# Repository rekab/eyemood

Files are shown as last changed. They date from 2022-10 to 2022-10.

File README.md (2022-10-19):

# eyemood

Video of a robot costume (https://www.youtube.com/watch?v=6ULORxLHcV8)

A thing to animate NeoPixel ring(s) with 12 LEDs.

Takes 5 input buttons (white, red, green, blue, yellow) that have LED
lights.

Together these represent the bits in a 5-bit integer, which is used
as an index of 32 different animations ("Steppers").

Each of the buttons have an LED that's lit based on if their bit is
a 1 (on) or 0 (off). This bit pattern changes by counting upwards by one
every ~8.7 seconds. It wraps back to 0 after 31.

## Requirements

### Hardware

* Tested on an Arduino UNO R3
* Two [NeoPixel 12 LED Rings](https://www.adafruit.com/product/1643)
* A 1000µF (6.3V or higher) capacitor on the power to the NeoPixel rings.
* A 470Ω resistor on the data pin to the NeoPixel rings.
* Five buttons. I used 5 diffent colors of
  [Mini LED Arcade Button - 24mm](https://www.adafruit.com/product/3432)
* [Micro USB pinboard](https://www.amazon.com/Pinboard-MELIFE-Interface-Adapter-Breakout/dp/B07W6T97HZ/)
  for powering the NeoPixel rings

### Arduino Libraries

* Reactduino (https://github.com/Reactduino/Reactduino)
* Adafruit Neopixel (1.10.5 https://github.com/adafruit/Adafruit\_NeoPixel)

### Wiring and Pins

|  Color | Purpose | Pin Number |
|:---:|:---:|:---:|
| Black  | white switch  | 11 |
| White  | white LED | 10 |
| Gray | green switch  | 9 |
| Purple | blue switch | 8 |
| Blue | blue LED | 7 |
| Green  | green LED | 6 |
| Yellow | yellow LED | 5 |
| Orange | yellow switch | 4 |
| Red | red LED | 3 |
| Brown  | red switch | 2 |

External power [must be connected to common ground](https://learn.adafruit.com/adafruit-neopixel-uberguide/basic-connections).

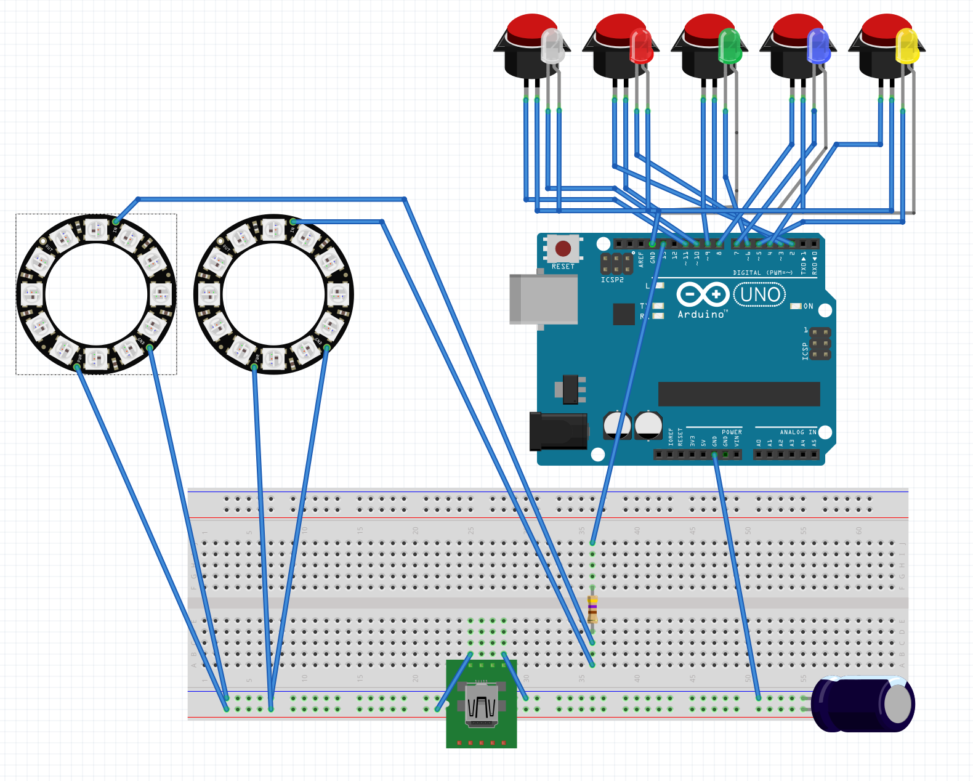
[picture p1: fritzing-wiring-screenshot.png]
Fritzing wiring diagram


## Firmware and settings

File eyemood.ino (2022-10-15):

/**
  * A thing to animate NeoPixel Ring(s) with 12 LEDs.
  *
  * Takes 5 input buttons (white, red, green, blue, yellow) that have LED
  * lights.
  *
  * Together these represent the bits in a 5-bit integer, which is used
  * as an index of 32 different animations ("Steppers").
  *
  * Each of the buttons have an LED that's lit based on if their bit is
  * a 1 (on) or 0 (off). This bit pattern changes by counting upwards by one
  * every ~8.7 seconds. It wraps back to 0 after 31.
  *
  * With debugging log statements this barely fit on an Arduino Uno, so they've
  * been mostly removed.
  *
  * 2022-10-02: Uploaded and put into costume. Not yet fastened down.
  */
#include <Reactduino.h>
#include <Adafruit_NeoPixel.h>

#define REPEAT_DELAY_MS 50
#define STEPS_UNTIL_CHANGE 175
#define BUTTON_DEBOUNCE_DELAY_MS 150

#define WHITE_MOOD_BUTTON_LED_PIN 10
#define WHITE_MOOD_BUTTON_SWITCH_PIN 11
#define WHITE_MOOD_BUTTON_SELECTOR_VALUE 4

#define RED_MOOD_BUTTON_LED_PIN 3
#define RED_MOOD_BUTTON_SWITCH_PIN 2
#define RED_MOOD_BUTTON_SELECTOR_VALUE 3

#define GREEN_MOOD_BUTTON_LED_PIN 6
#define GREEN_MOOD_BUTTON_SWITCH_PIN 9
#define GREEN_MOOD_BUTTON_SELECTOR_VALUE 2

#define BLUE_MOOD_BUTTON_LED_PIN 7
#define BLUE_MOOD_BUTTON_SWITCH_PIN 8
#define BLUE_MOOD_BUTTON_SELECTOR_VALUE 1

#define YELLOW_MOOD_BUTTON_LED_PIN 5
#define YELLOW_MOOD_BUTTON_SWITCH_PIN 4
#define YELLOW_MOOD_BUTTON_SELECTOR_VALUE 0

#define EYES_PIN 13
#define NUM_NEOPIXEL_PIXELS 12

#define COLOR_RED Adafruit_NeoPixel::Color(255, 0, 0)
#define COLOR_GREEN Adafruit_NeoPixel::Color(0, 255, 0)
#define COLOR_BLUE Adafruit_NeoPixel::Color(0, 0, 255)
#define COLOR_BLACK Adafruit_NeoPixel::Color(0, 0, 0)
#define COLOR_CYAN Adafruit_NeoPixel::Color(0, 150, 150)
#define COLOR_LIGHT_PURPLE Adafruit_NeoPixel::Color(200, 0, 100)
#define COLOR_WHITE Adafruit_NeoPixel::Color(255, 255, 255)


// Parameter 1 = number of pixels in strip
// Parameter 2 = Arduino pin number (most are valid)
// Parameter 3 = pixel type flags, add together as needed:
//   NEO_KHZ800  800 KHz bitstream (most NeoPixel products w/WS2812 LEDs)
//   NEO_KHZ400  400 KHz (classic 'v1' (not v2) FLORA pixels, WS2811 drivers)
//   NEO_GRB     Pixels are wired for GRB bitstream (most NeoPixel products)
//   NEO_RGB     Pixels are wired for RGB bitstream (v1 FLORA pixels, not v2)
Adafruit_NeoPixel eyes = Adafruit_NeoPixel(NUM_NEOPIXEL_PIXELS, EYES_PIN, NEO_GRB + NEO_KHZ800);
// IMPORTANT: To reduce NeoPixel burnout risk, add 1000 uF capacitor across
// pixel power leads, add 300 - 500 Ohm resistor on first pixel's data input
// and minimize distance between Arduino and first pixel.  Avoid connecting
// on a live circuit...if you must, connect GND first.

// Current animation being run.
uint8_t curStepper = 0;
// Steps since the stepper changed
uint32_t stepsSinceChange = 0;

uint8_t buttonToPinMap[5] = {
  /* button0: */ YELLOW_MOOD_BUTTON_LED_PIN,
  /* button1: */ BLUE_MOOD_BUTTON_LED_PIN,
  /* button2: */ GREEN_MOOD_BUTTON_LED_PIN,
  /* button3: */ RED_MOOD_BUTTON_LED_PIN,
  /* button4: */ WHITE_MOOD_BUTTON_LED_PIN,
};

unsigned long lastDebounceTime = 0;

reaction animationReaction = INVALID_REACTION;


// Class to step through an animation
class Stepper {
  protected:
  bool setupDone;

  // Animate setup. Returns true when setup is done.
  virtual bool setupStep() = 0;

  // Basic animation step.
  virtual void animationStep() = 0;

  void setAllPixelsToColor(uint32_t color) {
    for (uint8_t i = 0; i < NUM_NEOPIXEL_PIXELS; i++) {
      eyes.setPixelColor(i, color);
    }
  }

  public:
  Stepper() : setupDone(false) { }

  virtual bool resetToSetup() {
    setupDone = false;
  }

  virtual void step() {
    if (setupDone) {
      animationStep();
    } else {
      setupDone = setupStep();
    }
  }
};

class TwoColorRotatingStepper : public Stepper {
  uint8_t setupPixel, color1Start, color2Start;
  uint32_t color1, color2;

  public:
  TwoColorRotatingStepper(uint32_t color1, uint32_t color2) :
    setupPixel(0),
    color1Start(0),
    color2Start(NUM_NEOPIXEL_PIXELS / 2),
    color1(color1),
    color2(color2) {}

  virtual bool resetToSetup() {
    setupPixel = 0;
    Stepper::resetToSetup();
  }

  virtual bool setupStep() {
    // Color half the pixels color1, the other half color2
    eyes.setPixelColor(setupPixel,
        setupPixel < color2Start ? color1 : color2);
    eyes.show();
    setupPixel++;
    return setupPixel >= NUM_NEOPIXEL_PIXELS;
  }

  virtual void animationStep() {
    color1Start++;
    color1Start %= NUM_NEOPIXEL_PIXELS; // Have we walked off the end?
    eyes.setPixelColor(color1Start, color1);

    color2Start++;
    color2Start %= NUM_NEOPIXEL_PIXELS;
    eyes.setPixelColor(color2Start, color2);

    eyes.show();
  }
};

// Note: currently, only one illuminated pixel doesn't draw enough power to
// keep that USB battery on.
class OnePixelSpinner : public Stepper {
  uint32_t color;
  uint8_t curPixel;
  public:
  OnePixelSpinner(uint32_t color) : color(color), curPixel(0) {}

  virtual bool setupStep() {
    if (curPixel == 0) {
      eyes.setPixelColor(curPixel, color);
    } else {
      eyes.setPixelColor(curPixel, COLOR_BLACK);
    }
    eyes.show();
    curPixel++;
    return curPixel >= NUM_NEOPIXEL_PIXELS;
  }

  virtual void animationStep() {
    uint8_t prevPixel = curPixel % NUM_NEOPIXEL_PIXELS;
    ++curPixel %= NUM_NEOPIXEL_PIXELS;
    eyes.setPixelColor(prevPixel, COLOR_BLACK);
    eyes.setPixelColor(curPixel, color);
    eyes.show();
  }
};

class TwoPixelSpinner : public Stepper {
  uint32_t color;
  uint8_t curPixel;
  public:
  TwoPixelSpinner(uint32_t color) : color(color), curPixel(0) {}

  virtual bool setupStep() {
    if (curPixel == 0) {
      eyes.setPixelColor(curPixel, color);
    } else {
      eyes.setPixelColor(curPixel, COLOR_BLACK);
    }
    eyes.show();
    curPixel++;
    return curPixel >= NUM_NEOPIXEL_PIXELS;
  }

  virtual void animationStep() {
    uint8_t prevPixel = curPixel % NUM_NEOPIXEL_PIXELS;
    ++curPixel %= NUM_NEOPIXEL_PIXELS;
    eyes.setPixelColor(prevPixel, COLOR_BLACK);
    eyes.setPixelColor(curPixel, color);

    // do again for the opposite side
    uint8_t prevPixelOpp =
      (prevPixel + NUM_NEOPIXEL_PIXELS/2) % NUM_NEOPIXEL_PIXELS;
    uint8_t curPixelOpp =
      (curPixel + NUM_NEOPIXEL_PIXELS/2) % NUM_NEOPIXEL_PIXELS;
    eyes.setPixelColor(prevPixelOpp, COLOR_BLACK);
    eyes.setPixelColor(curPixelOpp, color);
    eyes.show();
  }
};
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

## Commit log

2022-09-25 add more buttons and button debouncing
2022-09-28 add steppers and a few basic animations
2022-10-02 minor cleanup; add timer-based debounce
2022-10-09 add fritzing diagram and comment header
    [wiring.fzz]
2022-10-09 tighten things up a bit
    [eyemood.ino]
2022-10-09 remove AA batteries, add png screenshot
    [wiring.fzz]
